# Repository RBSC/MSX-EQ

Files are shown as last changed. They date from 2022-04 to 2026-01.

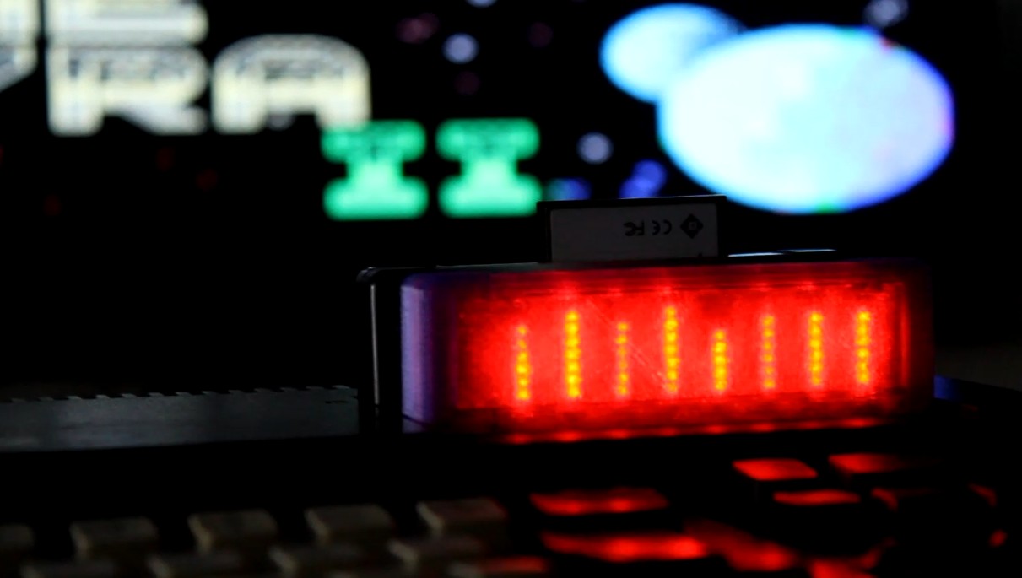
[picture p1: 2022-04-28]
Pics/MSX-EQ_Red_in_BlueCase.jpg

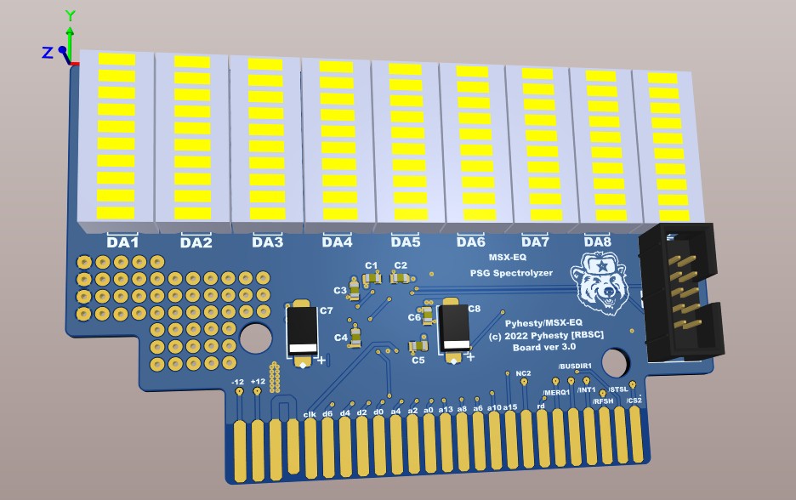
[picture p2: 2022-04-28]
Pics/MSX-EQ_v3pcb.jpg

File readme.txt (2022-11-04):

--------------------------------------------------------------------------------
MSX-EQ PSG Spectrolyzer Cartridge
Copyright (c) 2021-2022 RBSC
Developer: Pyhesty
Last update: 04.11.2022
--------------------------------------------------------------------------------

About the project
-----------------

The MSX-EQ PSG Spectrolyzer is a simple cartridge for the MSX platform that visualizes the spectrum of notes played by the
programmable sound generator, such as the AY-3-8910 or YM2149 (PSG). The cartridge board is intended for the standard MSX
cartridge slot. The board shows the effect of measuring the signal's level, in which each reproduced frequency (or frequency
range) corresponds to one of 9 vertical LED indicators.

All files of the MSX-EQ project are available in the RBSC's Github repository: 

 - https://github.com/RBSC/MSX-EQ

Hardware
--------
 
The MSX-EQ cartridge is based on the PLD Altera EPM7128, that has 128 logical units. The PLD intercepts PSG port I/O, identifies
the played note/frequency and displays its representation on the dedicated LED indicator. The cartridge doesn't need any special
setup. It can be installed into any standard MSX slot that allows an unobstructed view of the cartridge's LED indicators.

The cartridge visualizes the played notes/frequencies in games and demos in real time. After a note/frequency fades out, the LED
indicators automatically switch off.

The cartridge may be assembled in 2 different ways:

 - With discrete LED elements - simple, but allowing various color combinations
 - With LED assemblies - the so-called "bars", mostly single-colored

The following color combinations are possible (those were tested and were found suitable for the project, however other color
combinations are possible):

 - One color LEDs or LED assemblies: blue, red or green
 - Multi-colored LEDs or LED assemblies: blue with red or green with red (red LEDs are placed on top)

Firmware uploading
------------------

The freshly-assembled MSX-EQ cartridge needs the firmware to be uploaded into the PLD chip. For updating/uploading the firmware
into the cartridge you will need:

 - Quartus II Web Edition (Free) v15.0 or later software
 - Byte Blaster or USB Blaster programmer (can be purchased on Ebay or AliExpress)

The procedure is simple - supply 5v onto the cartridge board, connect the USB Blaster to the JTAG connector's placeholder (mind
the orientation of the connector!). Auto-detect the Altera chip with Quatrus software and then upload the POF file from the
"Firmware" folder into the PLD chip.

The Quartus Programmer software can be downloaded from here:

 - https://mirrors.pdp-11.ru/_msx/_carnivore2/quartus/

IMPORTANT!
If the LED assemblies with inverted polarity were used to assemble the cartridge, please use the "MSX_EQ_inv_led.pof" firmware
instead of the standard one.

Assembling notes
----------------

It's highly recommended to install all ceramic capacitors (100nF) onto the board. In addition, at least one tantalum capacitor should
be installed.

Cartridge case
--------------

Any factory-made MSX cartridge manufactured from semi-transparent or transparent plastic is suitable for the MSX-EQ cartridge board.
For example, the following quality MSX cartridge cases can be obtained from Overrich (South Korea) and Retro Game Restore (Taiwan):

 - https://retrogamerestore.com/store/msx_cart_shell/
 - https://www.msx.org/news/en/black-white-and-transparent-msx-cartidge-cases-overrich

Also, there's a 3D model of the cartridge case in the repository. The case should be printed with semi-transparent filament.

Where to buy parts
------------------

All parts for assembling the MSX-Eq cartridge can be purchased from varios sellers on AliExpress:

1. PLD: EPM7128STC100
2. LEDs: single 0805 size LEDs or LED assemblies
3. Resistors: 0805 1k
4. Capacitors: 0805 0.1uF
5. Tantalum capacitors: TypeB or TypeC, 10-100uF

See the partslist.txt document for more info.

Visual Effects
--------------

You can check how the cartridge visualizes various PSG effects by watching these videos:

 - Games: https://youtu.be/E50GIDputWo
 - Demo 1: https://youtu.be/SXDI22wPhJE
 - Demo 2: https://youtu.be/Vhv5bKJgaLk

IMPORTANT!
----------

The RBSC provides all the files and information for free, without any liability (see the disclaimer.txt file). The provided information,
software or hardware must not be used for commercial purposes unless permitted by the RBSC. Producing a small amount of bare boards for
personal projects and selling the rest of the batch is allowed without the permission of RBSC.

When the sources of the tools are used to create alternative projects, please always mention the original source and the copyright!

If you would like to commercially produce this cartridge, please contact the administrator of the RBSC (see info below).

Contact information
-------------------

The members of RBSC group Tnt23, Wierzbowsky, Pyhesty, Ptero, GreyWolf, SuperMax, VWarlock and DJS3000 can be contacted via the group's e-mail
address:

info@rbsc.su

The group's coordinator could be reached via this e-mail address:

admin@rbsc.su

The group's website can be found here:

https://rbsc.su/
https://rbsc.su/ru

The RBSC's hardware repository can be found here:

https://github.com/rbsc

The RBSC's 3D model repository can be found here:

https://www.thingiverse.com/groups/rbsc/things

-= ! MSX FOREVER ! =-

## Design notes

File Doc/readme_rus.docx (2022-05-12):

MSX-EQ PSG Spectrolyzer для платформы MSX

Разработчик: Pyhesty [RBSC]. Copyright (C) 2022

Для получения дополнительной информации мы рекомендуем прочитать английский readme.txt файл из репозитория

О проекте

MSX-EQ PSG Spectrolyzer – это простой картридж визуализатора спектра нот, воспроизводимых программируемым звуковым генератором типа AY-3-8910 или YM2149 (PSG). Плата предназначена для установки в стандартный MSX слот. Плата воспроизводит эффект измерения уровня сигнала, при котором каждой воспроизводимой частоте (диапазону частот) соответствует один из девяти вертикальных светодиодных индикаторов. После воспроизведения ноты или частоты индикатор плавно затухает.

Возможны две версии исполнения картриджа:

1. На дискретных светодиодных элементах; более простая, но позволяющая реализовать различные цветовые решения
2. На светодиодных сборках, так называемых "bar", в большинстве своём одноцветных

Возможны следующие цветовые решения, которые были нами опробованы и дали хороший визуальный эффект (также возможны и другие цветовые решения):

1. Одноцветные светодиоды или светодиодные сборки синего, красного или зелёного цветов
2. Многоцветные светодиодные сборки или комбинации отдельных светодиодов: синего с красным или зеленого с красным (красные светодиоды размещаюся сверху)

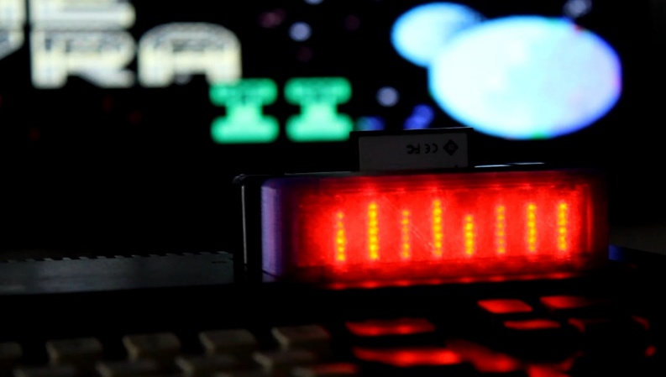
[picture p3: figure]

Картридж MSX-EQ создан на базе PLD Altera EPM7128, состоящей из 128 логических блоков и регистров. PLD анализирует запись в порты звукового генератора, вычисляет соответствующую ноту (частоту) и визуализирует её на соответствующем светодиодном индикаторе.

Картридж не требует никаких дополнительных настроек. Он устанавливается в любой свободный MSX слот, позволяющий иметь хороший обзор верхней передней части картриджа (там расположены индикаторы). При проигрывании музыки, например в играх или демонстрационных программах, картридж в режиме реального времени визуализирует спектр используемых частот (нот). После завершения музыкальной композиции индикаторы гаснут автоматически.

В качестве корпуса для MSX-EQ подходит любой промышленно выпускаемый полупрозрачный корпус для MSX картриджа, например корпус от Retro Game Restore или от Overrich:

- https://retrogamerestore.com/store/msx_cart_shell/
- https://www.msx.org/news/en/black-white-and-transparent-msx-cartidge-cases-overrich

Для этого картриджа также подходит корпус из полупрозрачного пластика, распечатанный на 3Д принтере. Модель можно найти в репозитории.

Демонстрацию работы картриджа можно посмотреть здесь:

- Игры: https://youtu.be/E50GIDputWo
- Демо 1: https://youtu.be/SXDI22wPhJE
- Демо 2: https://youtu.be/Vhv5bKJgaLk

Все файлы проекта MSX-EQ доступны для некоммерческого использования в репозитории группы RBSC по этому адресу:

- https://github.com/RBSC/MSX-EQ

По вопросам коммерческого использования или изготовления картриджа необходимо обратиться к администратору группы RBSC (см. ниже).

ВАЖНО!!

Группа RBSC предоставляет всю информацию и файлы бесплатно, без каких-либо обязательств или гарантий. Предоставленная информация и (или) файлы не могут быть использованы в коммерческих целях без согласования с автором проекта. Изготовление нескольких плат картриджа для себя или друзей не возбраняется. Продажа остатков партии несобранных плат также разрешена без каких-либо выплат авторам.

Как с нами связаться

С членами группы RBSC - Tnt23, Wierzbowsky, Pyhesty, Ptero, GreyWolf, SuperMax и DJS3000 можно связаться по этому адресу электронной почты: info@rbsc.su

С координатором группы RBSC, например по вопросам коммерческого использования проектов группы, можно связаться по этому адресу электронной почты: admin@rbsc.su

Официальный вебсайт группы RBSC находится по этому адресу:

- https://rbsc.su/
- https://rbsc.su/ru (русская версия)

Официальный репозиторий проектов группы RBSC находится по этому адресу:

- https://github.com/rbsc

Репозиторий 3Д моделей группы RBSC находится по этому адресу:

- https://www.thingiverse.com/groups/rbsc/things

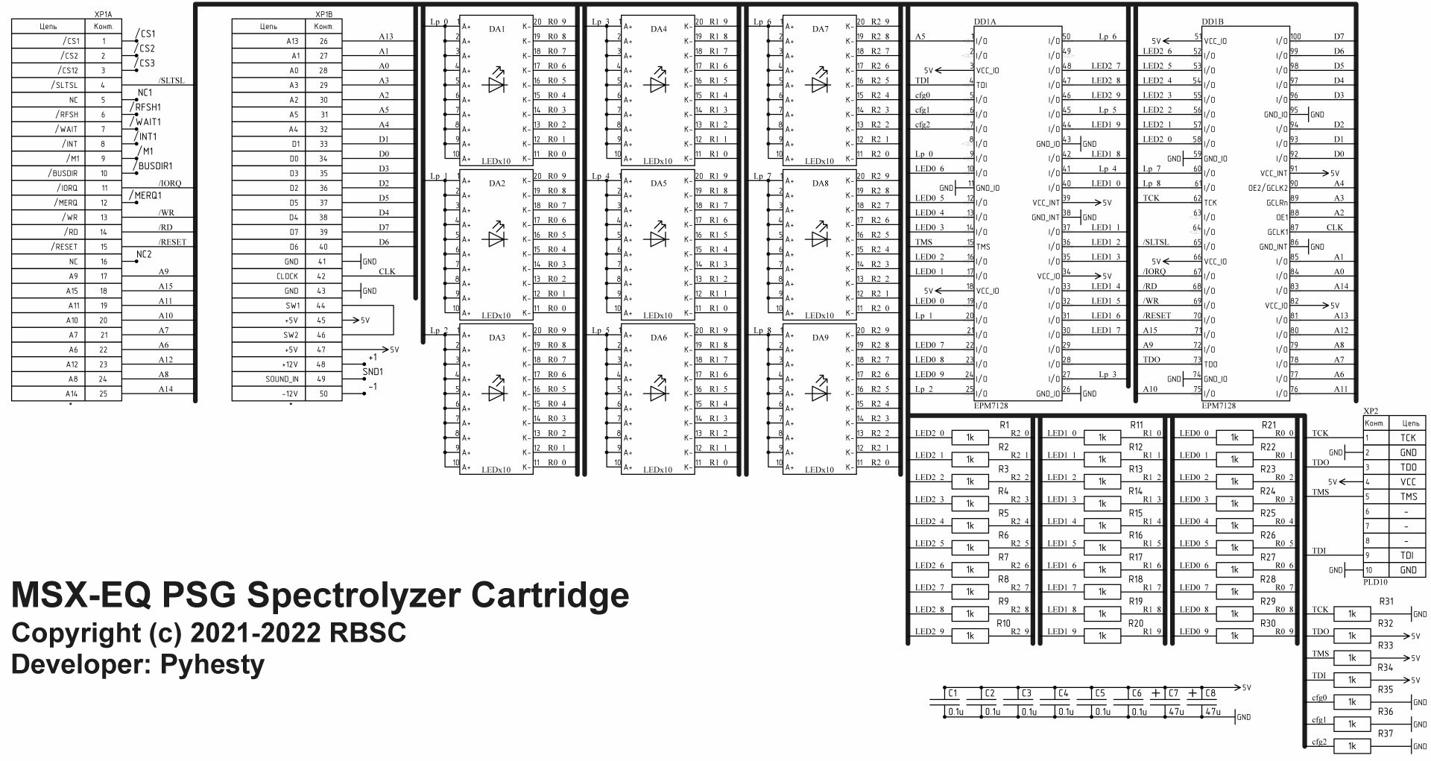
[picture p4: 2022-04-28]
Doc/schematics.jpg

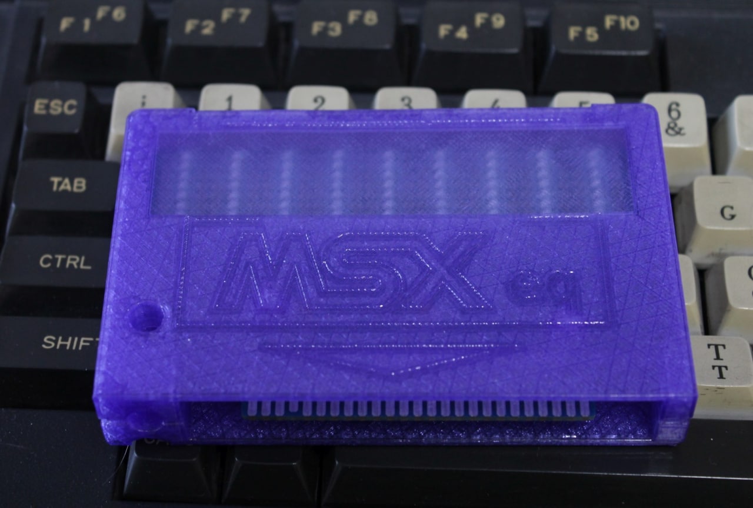
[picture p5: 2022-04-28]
Pics/MSX-EQ.jpg

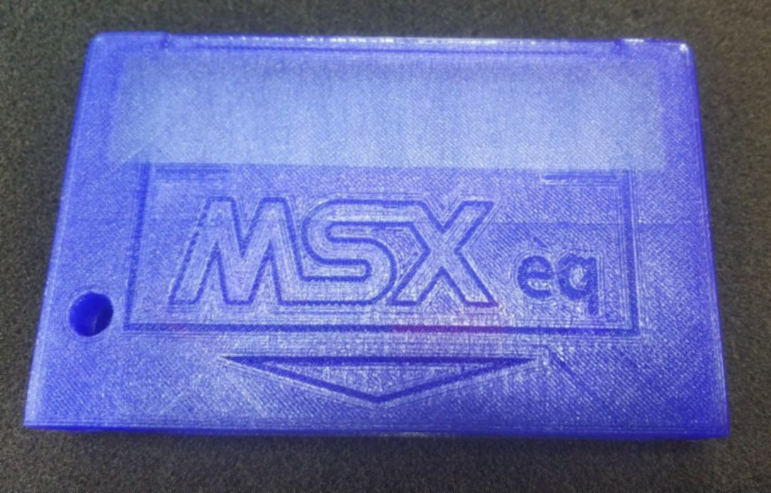
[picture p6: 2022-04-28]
Pics/MSX-EQ_case.jpg

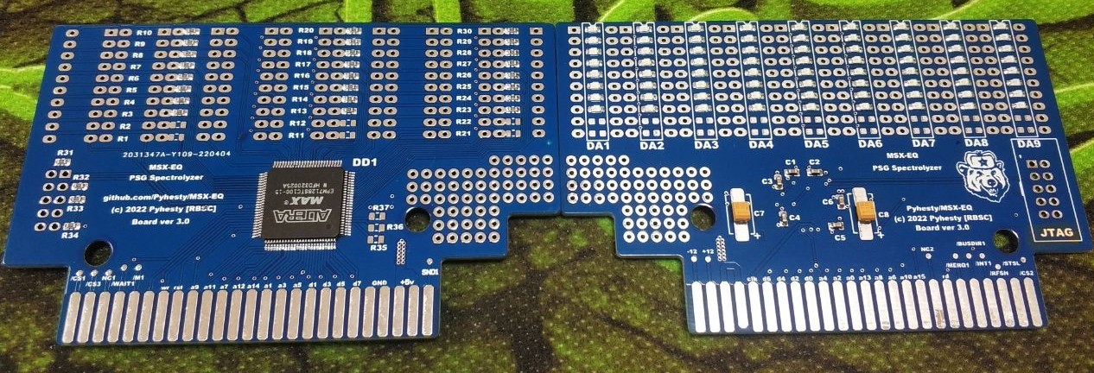
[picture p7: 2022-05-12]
Pics/MSX-EQ_realboard_v3.jpg

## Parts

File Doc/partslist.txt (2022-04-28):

--------------------------------------------------------------------------------
MSX-EQ PSG Spectrolyzer Cartridge
Copyright (c) 2021-2022 RBSC
--------------------------------------------------------------------------------

Partlist
--------

Part     Value           Device               Package      Library         Count
--------------------------------------------------------------------------------
C1..C6   100nF           C-EUC0805            C0805        rcl             6
C7..C8   47uF 10v        CPOL-EUSMCB          SMC_B        rcl             2
DA1..DA9   LEDs          2010BB               DIP-8                        9
D1         PDL           EPM7128STC100        TSOP-100     IC              1
R1..R37  1k              R-EU_R0805           R0805        resistor        37
XP2      PIN-10          PLD10                             XP              1   
MSXSLOT                  EDGE-CONNECTOR                    50-pin slot     1

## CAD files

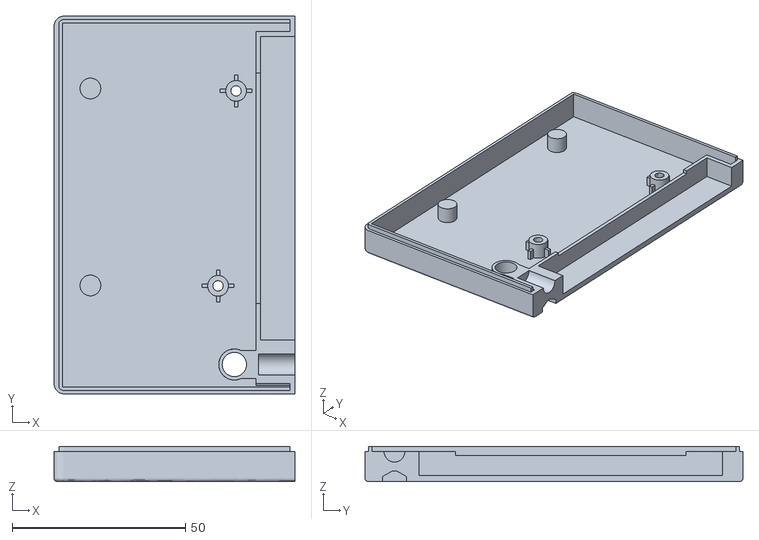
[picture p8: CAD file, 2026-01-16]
Case/MSXEQ_TRH_Top.stl
69.5 x 109.0 x 10.1

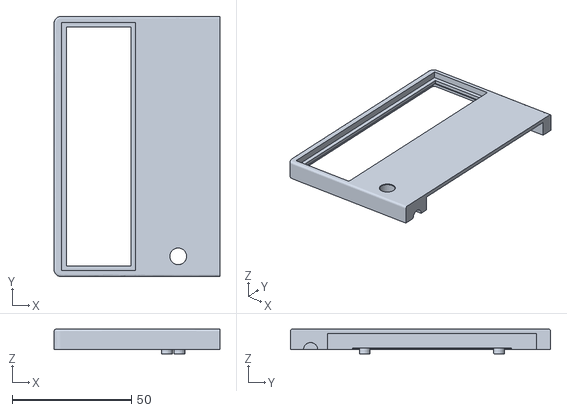
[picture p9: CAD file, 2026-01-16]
Case/MSXEQ_TRH_Bottom.stl
69.5 x 109.0 x 10.4

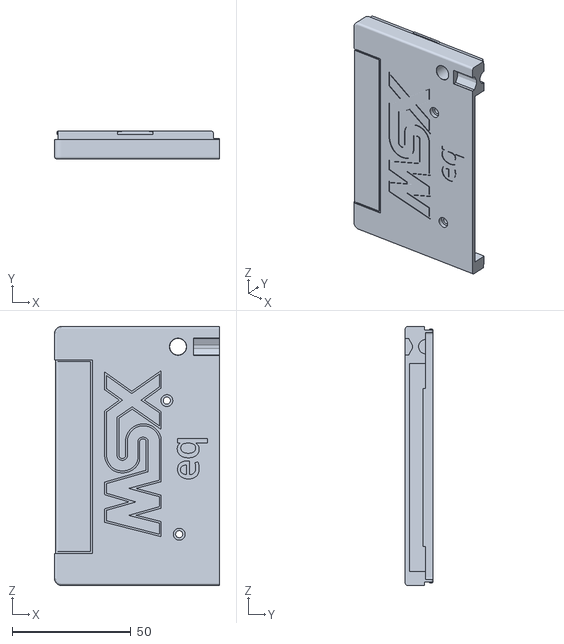
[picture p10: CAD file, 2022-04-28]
Case/MSXEQ_Case_bottom.STL
69.5 x 11.6 x 109.0

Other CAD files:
Case/MSXEQ_Case_top.STL

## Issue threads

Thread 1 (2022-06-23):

Altera EPM7128STC100-15n

jgilcas, 2022-06-23:
Is posible to create a firmware for -15n model? I don't know if this speed grade can be used in first place but I tried to upload .pof file and I got an error.

Thanks in advance.

Wierzbowsky, 2022-07-03:
Speed doesn't matter. If the chip has the same model, the firmware should be uploaded without a problem. Did you supply 5v power onto the board before trying to upgrade the firmware?

Wierzbowsky, 2022-07-04:
Your chip is identified as EPM7128ST100, but in our partslist the chip is EPM7128STC10. Probably this is the reason.

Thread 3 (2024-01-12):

First DA1 led bar never lites on

PicoElements, 2024-01-12:
Hello.
I love this project and i succeded in building a board with led bars. Actually i'm trying with a Toshiba HX-20 using King's Valley as a game in the second slot and the MSX-EQ board in the first slot.

Tha strange thing is that only the first  led bar is not working, all the others work. I tested the led orientation and is with negative on the right for each bar. Maybe the game is not using the frequencies at DA1 ? Maybe some bad joint? Can you suggest me a game i could use to be sure the first bar is used?

Thanks a lot for your help,
Stefano

PicoElements, 2024-01-12:
Thank you Dmitri for your answer! I will try to build another board the or swap the PLD.
I'm using 10 led bar and i've filled the board with 1k resistors also if i noticed that only 8 leds are used. Could it be an issue?
Thnks!

Closed 2024-01-12.

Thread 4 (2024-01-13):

Cartridge case

PicoElements, 2024-01-13:
Hello!
I have printed the cartridge case, but since i used bar leds (10 led per bar), the cartridge case won't fit.
So ... i would ask if it's possible to have a cartridge case with a larger window for leds and if it's possible you will handle all the 10 leds, it would be really amazing!!!

Thanks for your great kindness!
PE

Closed 2024-01-17.

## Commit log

2022-04-28 Initial release 28.04.2022
    MSX-EQ PSG Spectrolyzer Cartridge initial release
    [MSXEQ_Case_bottom.STL, MSXEQ_Case_top.STL]
2022-05-12 Update 12.05.2022
    Updated readme, added real board photos and firmware with for inversed
    LEDs
2026-01-11 Add new option for the cartridge case that combines 3D printing and an acrylic visor.
    [MSXEQ_TRH_Bottom.stl, MSXEQ_TRH_Top.stl]
